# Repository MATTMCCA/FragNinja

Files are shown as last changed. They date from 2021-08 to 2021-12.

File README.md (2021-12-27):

# Frag-Ninja

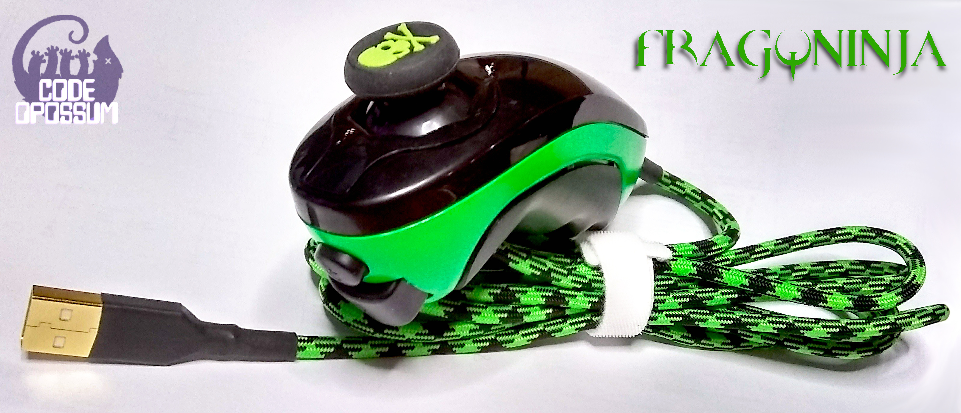
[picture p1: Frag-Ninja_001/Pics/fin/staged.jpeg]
STAGED


Wii Nunchuk 2 USB HID device, modchip repo. 

This board prototype should fit **in** a wii Nunchuk controller, ~~*I did not double check the clearance*~~.  

The Goal is to use the Nunchuk controller as a USB HID keyboard *OR* USB HID Gamepad, after connecting the *mod-chip*. 
The nunchuk also has 3 axis motion control. *(This, I'm not interested in)*.

[Digikey Cart with Reference Designators](https://www.digikey.com/short/zw3pv2)

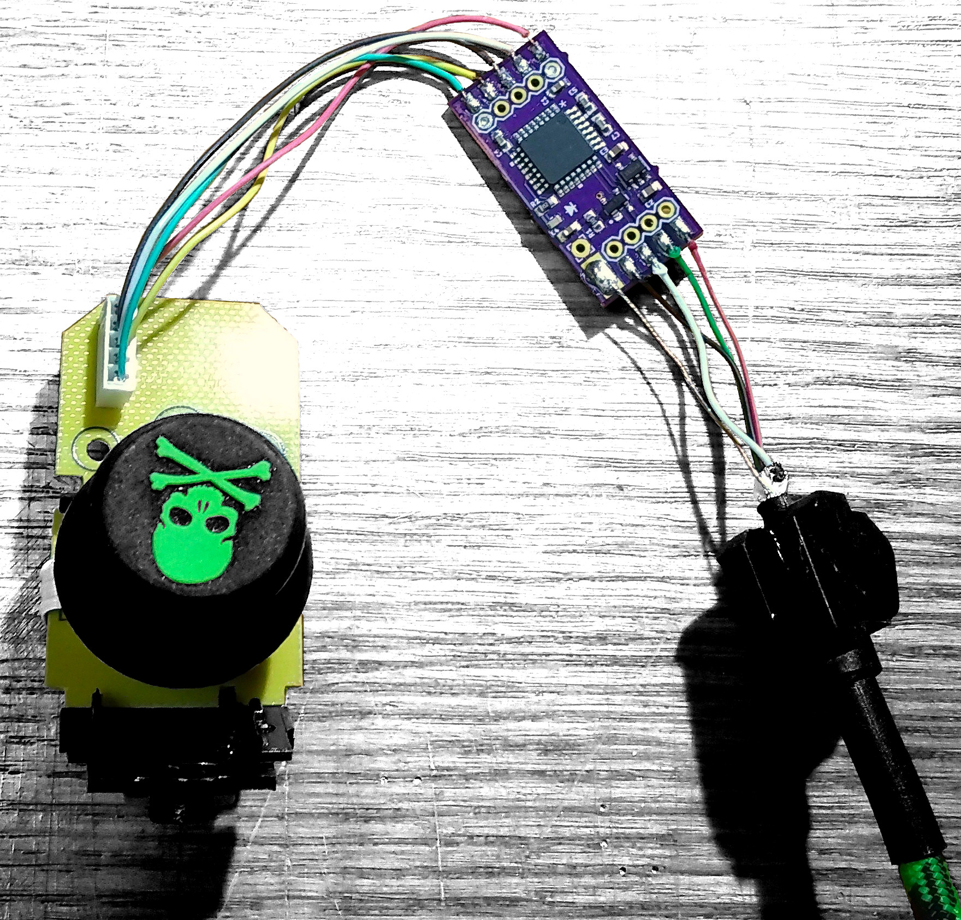
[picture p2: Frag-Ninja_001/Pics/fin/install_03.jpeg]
<p>

[*I'm not making kits, its too much work*](https://memegenerator.net/img/instances/65580880/not-sure-if-its-too-much-work-or-im-just-too-lazy.jpg)

---

### Notes
~~Using the the controllers attached cable is an option~~, but I opted for a new, longer, shielded, USB cable.

USB cable assembly parts purchased from [ZapCables.com](https://zapcables.com/diy-usb-cable-kit/)

- Cable length: ~~3ft~~, 6'
- USB Type-A connector (Gold Plated)
- Cord color: ~~'Acid Purple'~~, 'Viper'
- Double Sleeving: ~~Techflex, Ogre~~, None
- HeatShrink: ~~Purple~~, Black

Cable Build Guide: https://zapcables.com/content/zap-diy-usb-cable-kit-guide-v1.pdf

- **I think I linked the wrong LED in the BOM**.

---
### To Flash The Adafruit Bootloader

Solder Wires to **SWCLK & SWDIO**. Vref connects to pad **VCC** (this is 3.3vdc). Then supply 5vdc to the **5v** pad, and ground to the **GND** pad

I used this [Guide](https://learn.adafruit.com/how-to-program-samd-bootloaders/trinket-m0-wiring) & this [Guide](https://learn.adafruit.com/how-to-program-samd-bootloaders/programming-the-bootloader-with-atmel-studio) as a reference. Since Frag-Ninja is basically a clone of the *Trinket M0*, the procedure is exactly the same.

---

#### See Bill of Materials for board assembly part numbers.

- [Wii Nunchuck Controller](https://www.amazon.com/gp/product/B07RLBN9Z2)
- [Analog Thumb Stick Caps](https://www.amazon.com/gp/product/B07Q2B2VY4)
- [Skull Cap Covers](https://www.amazon.com/gp/product/B07GS95TD1)

### More Info
This 'mod-chip' is based on the *adafruit Trinket M0*, as a result I am able to use their boot-loader & arduino libs. This makes life just a tad bit easier (less code). 

*Big thanks to Adafriut for all of their hard work and great products.*

## Work in Progress

-  Boards have been ordered (9/13/2020)
   - BOARDS CAME! (9/26/2020)
---
-  Parts have been ordered (9/13/2020)
---
-  USB Cable kit has been ordered (9/13/2020)
   - *Cable Assembled, I should have got a 5' cable (9/17/2020)*
      - *was replaced with a 6' cable (9/23/2020)*
---	  
- **NEED TO ASSEMBLE THE PCB**
   - *PCB assembled (9/26/2020)*
---   
- **NEED TO BURN THE BOOTLOADER**
   - *Bootloader burned (9/26/2020)*
---   
- **NEED TO TEST THE HARDWARE**
   - *Tested and working (9/26/2020)*
---   
- **NEED TO FLASH CODE**
   - *Code tested & working (9/26/2020)*
---   
- **NEED TO HACK APART A WII Nunchuk**
   - *Gave a new white controller a fresh coat of lime green paint (9/24/2020)*
   - *Test fitted an **Xbox 360** after-market 'Analog Thumb Stick Cap' (9/24/2020)*.
   - *Frag-Ninja ModChip installed and working (9/26/2020)*
---
- **NEED TO FRAG!**



# WHY!?

Because I can't find a cheap joystick! I guess they aren't cool anymore or something.

# Copyright

Everything in this repo is released under Creative Commons Attribution-ShareAlike 2.5 Generic (CC BY-SA 2.5).

Comes as is, no warranty. I am also not responsible for any spontaneous time travel or combustion.

*Moved from my old repo*

### Borrowed works maintain original license.

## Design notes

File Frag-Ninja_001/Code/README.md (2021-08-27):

# Frag-Ninja

**Frag-Ninja** uses an ARM Cortex-M0+ SAM D21E from Microchip.

As lady luck would have it, there is Arduino core support for this chip. 

The provided code is written in C++, using Arduino libraries, see source headers for details.

### Notes

*I **HAVE** tested the code on the Frag-Ninja boards.*

#### HID GamePad Source Code
- Frag-Ninja_DPAD_8POS
- Frag-Ninja_JOYSTICK

#### HID Keyboard Source Code
- Frag-Ninja_KEYBOARD

## Why Arduino?
Because the hardware support is there, and its popular. OH! and the *OpenSource thing* helps too.

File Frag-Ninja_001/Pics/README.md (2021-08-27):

# Gallery

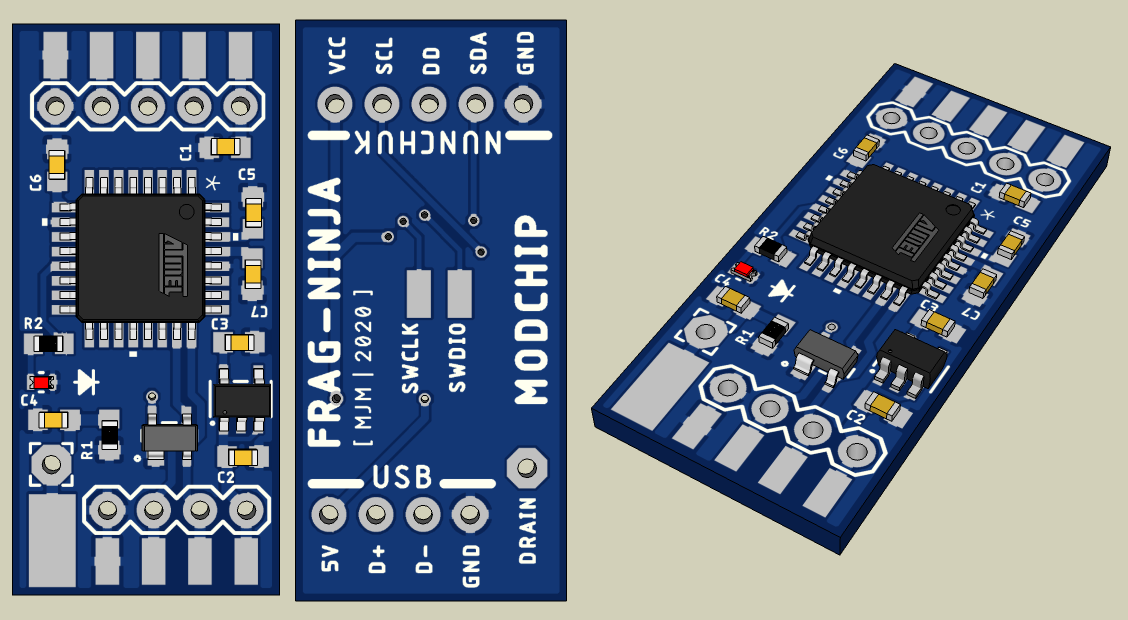
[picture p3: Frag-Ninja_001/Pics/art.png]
<p>

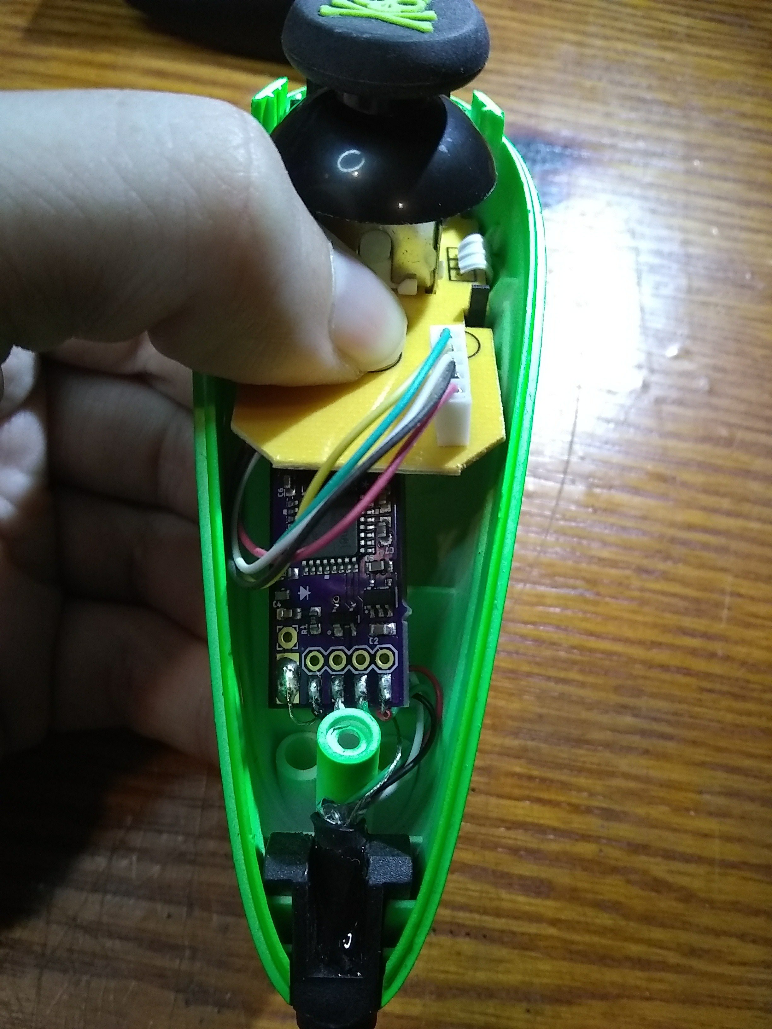
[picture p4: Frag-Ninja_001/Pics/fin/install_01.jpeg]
<p>

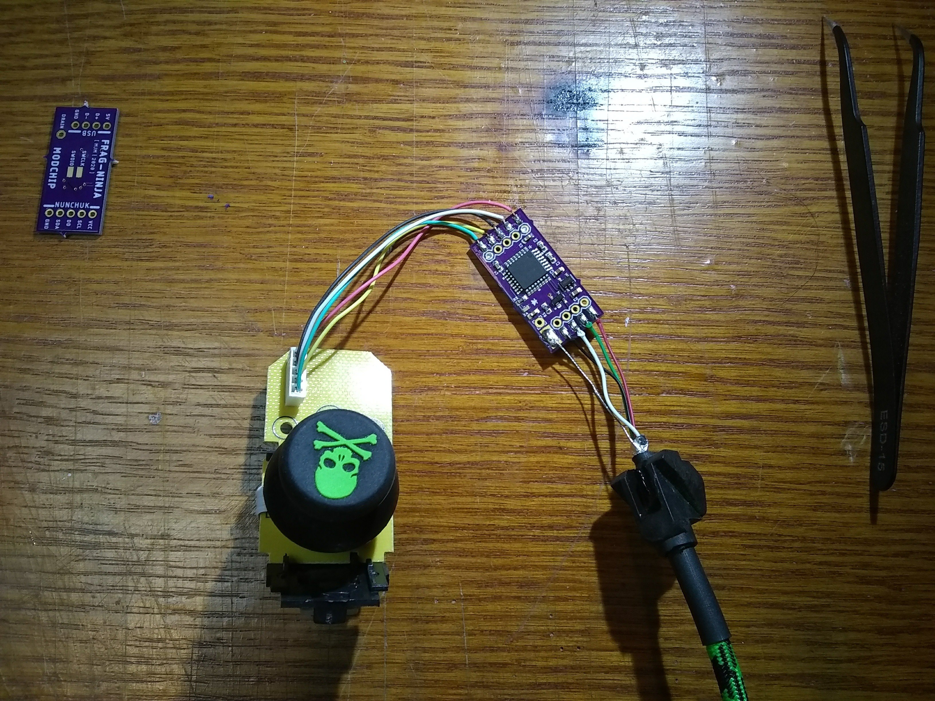
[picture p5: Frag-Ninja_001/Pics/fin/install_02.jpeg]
<p>

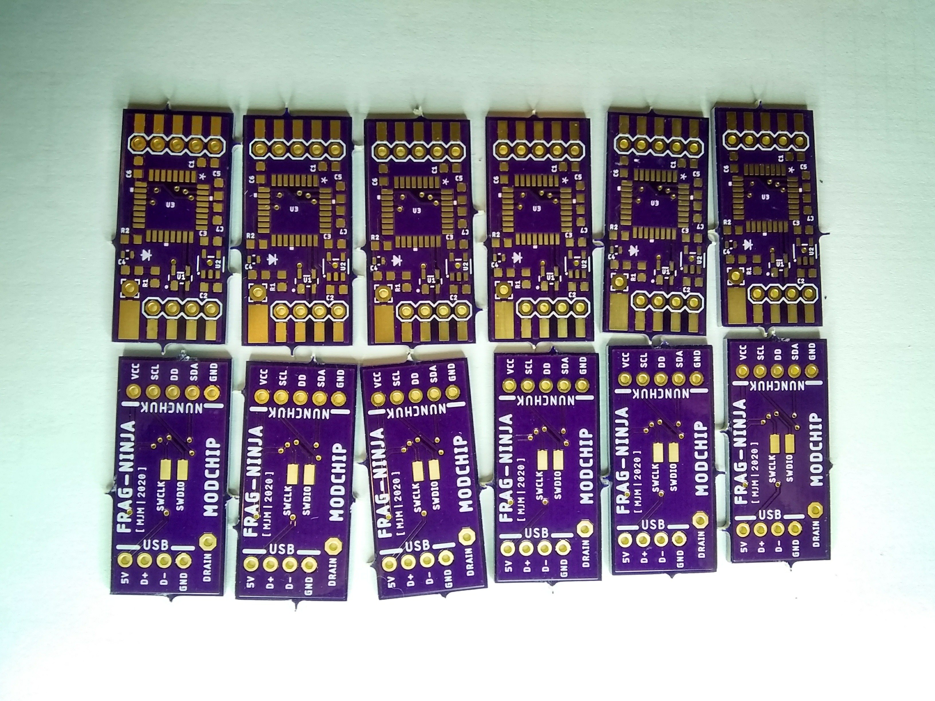
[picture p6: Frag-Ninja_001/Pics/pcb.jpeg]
<p>

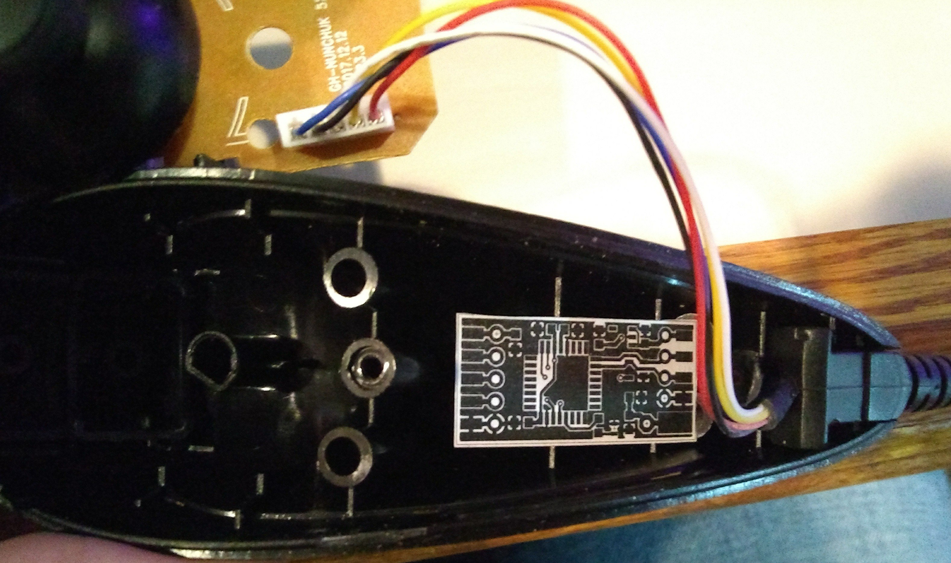
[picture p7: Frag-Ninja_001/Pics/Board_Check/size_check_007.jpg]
<p>

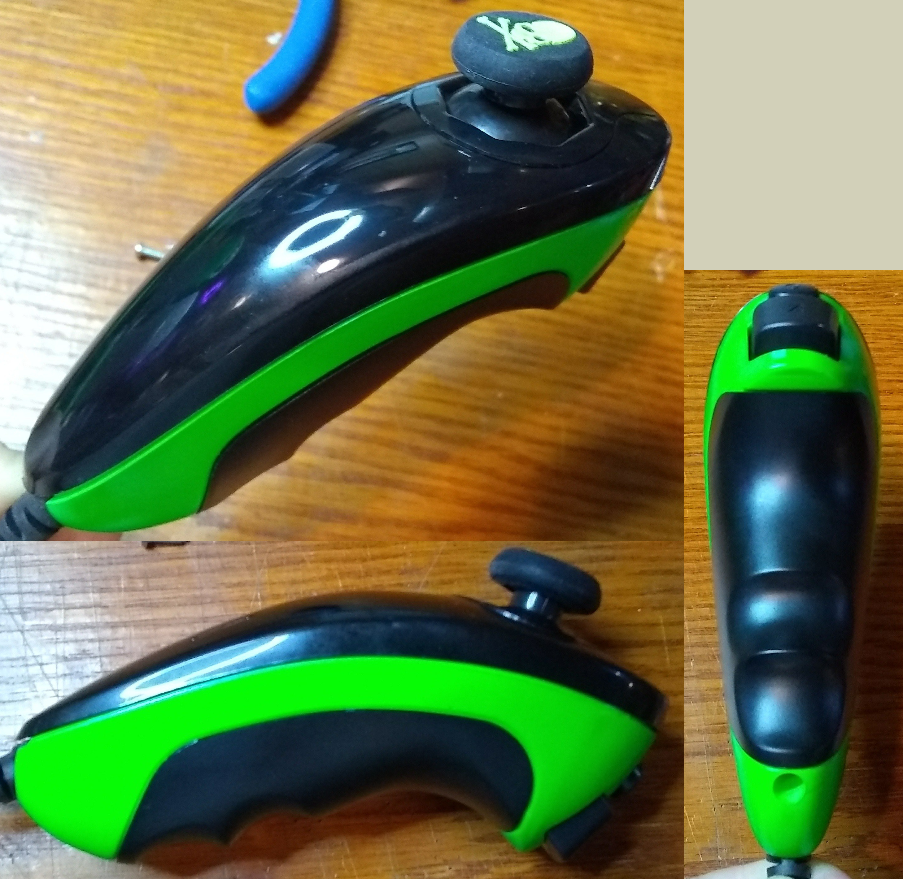
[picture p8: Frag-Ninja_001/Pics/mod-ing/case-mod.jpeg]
<p>

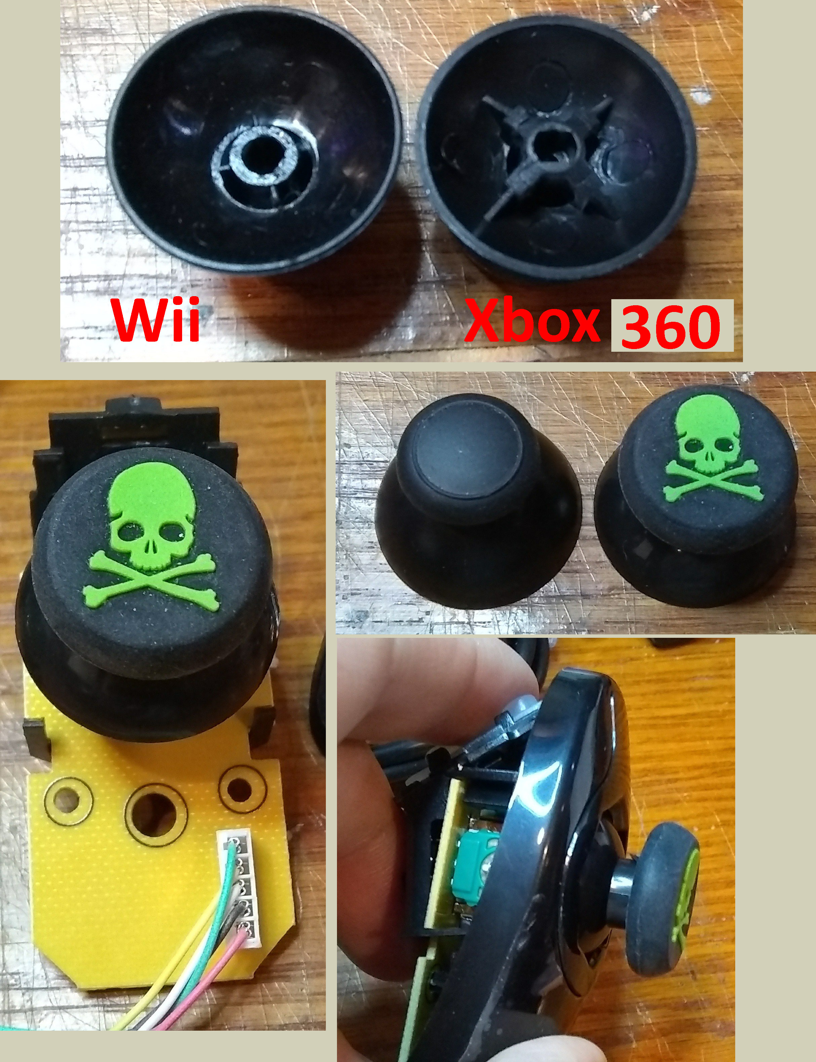
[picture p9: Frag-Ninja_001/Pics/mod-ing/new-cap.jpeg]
<p>

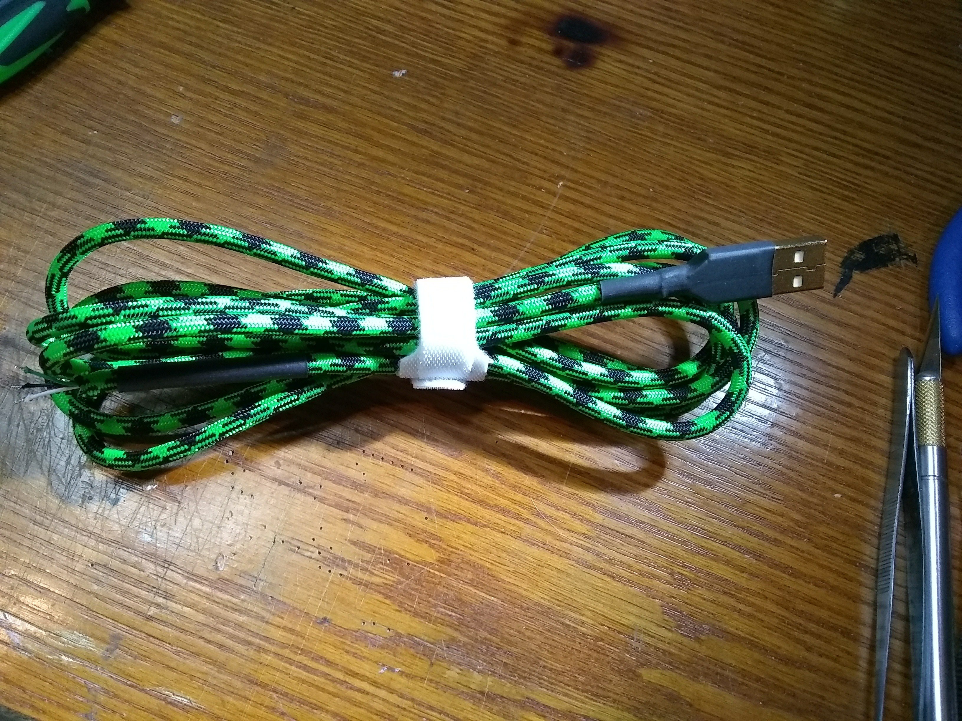
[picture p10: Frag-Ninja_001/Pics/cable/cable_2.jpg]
<p>

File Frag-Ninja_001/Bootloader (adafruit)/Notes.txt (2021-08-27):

- Notes -
https://learn.adafruit.com/how-to-program-samd-bootloaders/programming-the-bootloader-with-atmel-studio
https://learn.adafruit.com/how-to-program-samd-bootloaders/trinket-m0-wiring

https://learn.adafruit.com/assets/45723
https://www.adafruit.com/product/3500

- Bootloader -
https://github.com/adafruit/uf2-samdx1/releases/tag/v3.10.0

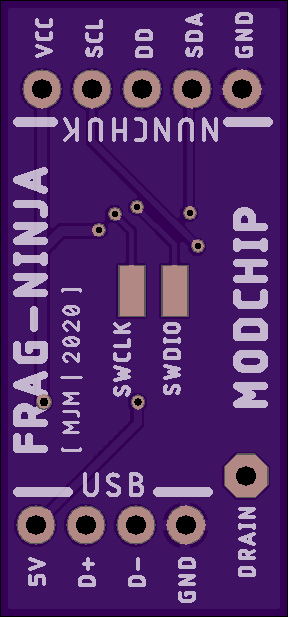
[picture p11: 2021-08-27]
Frag-Ninja_001/Pics/oshpark_back.png

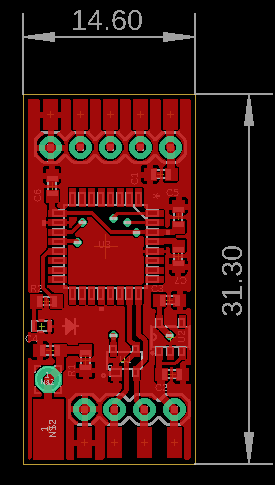
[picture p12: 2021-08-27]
Frag-Ninja_001/Pics/BRD_TOP.png

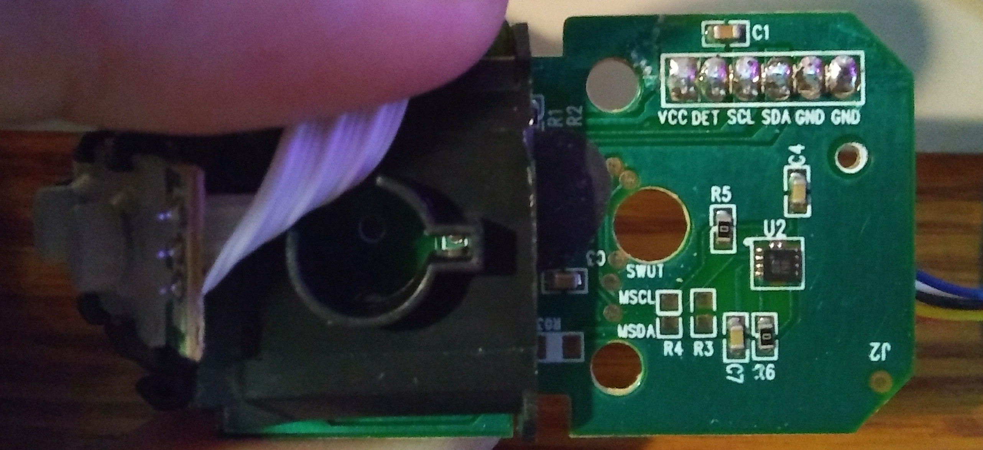
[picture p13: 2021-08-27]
Frag-Ninja_001/Pics/Board_Check/size_check_004.jpg

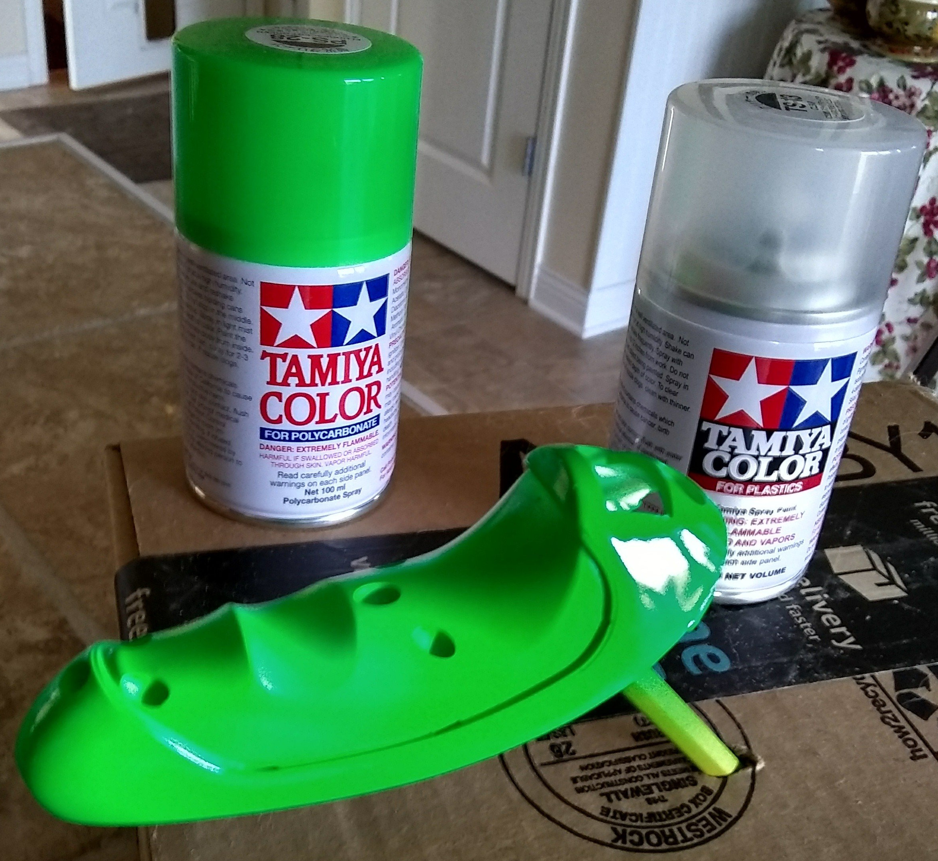
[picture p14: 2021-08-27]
Frag-Ninja_001/Pics/mod-ing/paint.jpeg

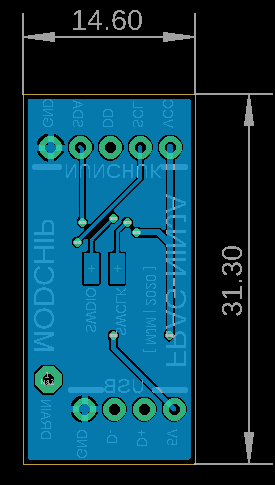
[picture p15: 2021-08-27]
Frag-Ninja_001/Pics/BRD_BOT.png

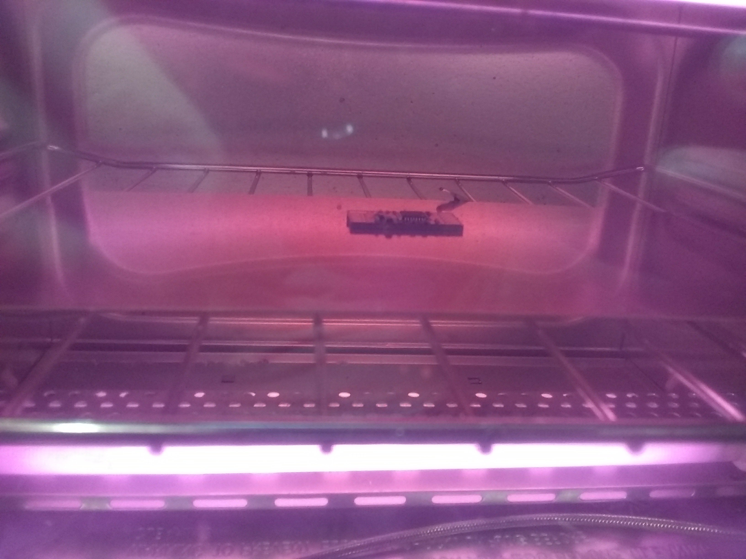
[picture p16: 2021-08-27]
Frag-Ninja_001/Pics/Board_Check/reflow.jpeg

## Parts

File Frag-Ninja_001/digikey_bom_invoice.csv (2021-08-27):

Index | Quantity | Part Number | Manufacturer Part Number | Description | Customer Reference | Backorder | Unit Price | Extended Price
1 | 50 | 1276-1182-1-ND | CL10A105KP8NNNC | CAP CER 1UF 10V X5R 0603 | C1, C5, C6, C7 | 0 | 0.0208 | $1.04
2 | 10 | 445-14258-1-ND | C1608X7S1A475K080AC | CAP CER 4.7UF 10V X7S 0603 | C2, C3 | 0 | 0.174 | $1.74
3 | 50 | 399-1087-1-ND | C0603C472K5RACTU | CAP CER 4700PF 50V X7R 0603 | C4 | 0 | 0.0226 | $1.13
4 | 10 | SML-D12U1WT86CT-ND | SML-D12U1WT86 | LED RED DIFFUSED 1608 SMD | LED1 | 0 | 0.147 | $1.47
5 | 10 | A130452CT-ND | CRGP0603F1M0 | CRGP 0603 1M0 1% | R1 | 0 | 0.121 | $1.21
6 | 100 | A130092CT-ND | CRGCQ0603J1K5 | CRGCQ 0603 1K5 5% | R2 | 0 | 0.0083 | $0.83
7 | 5 | 1727-3884-1-ND | PRTR5V0U2X,215 | TVS DIODE 5.5V SOT143B | U1 | 0 | 0.51 | $2.55
8 | 5 | AP7365-33WG-7DICT-ND | AP7365-33WG-7 | IC REG LINEAR 3.3V 600MA SOT25 | U2 | 0 | 0.42 | $2.10
9 | 3 | ATSAMD21E18A-AU-ND | ATSAMD21E18A-AU | IC MCU 32BIT 256KB FLASH 32TQFP | U3 | 0 | 2.91 | $8.73
 |  |  |  |  |  |  | Subtotal | $20.80

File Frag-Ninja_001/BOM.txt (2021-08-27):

Partlist

Exported from FN_001.sch at 9/13/2020 12:08 AM

EAGLE Version 9.5.0 Copyright (c) 1988-2019 Autodesk, Inc.

Assembly variant: 

Part     Value               Device              Package        Library             Sheet       Digikey Part#

C1       1uF                 C-EUC0603K          C0603K         rcl                 1           1276-1182-1-ND

C2       4.7uF               C-EUC0603K          C0603K         rcl                 1           445-14258-1-ND
C3       4.7uF               C-EUC0603K          C0603K         rcl                 1           445-14258-1-ND

C4       4.7nF               C-EUC0603K          C0603K         rcl                 1           399-1087-2-ND

C5       1uF                 C-EUC0603K          C0603K         rcl                 1           1276-1182-1-ND
C6       1uF                 C-EUC0603K          C0603K         rcl                 1           1276-1182-1-ND
C7       1uF                 C-EUC0603K          C0603K         rcl                 1           1276-1182-1-ND

LED1     RED                 SML-D12U1WT86       LED_SMLD12_ROM SML-D12U1WT86       1           SML-D12U1WT86CT-ND

R1       1M                  R-US_R0603          R0603          rcl                 1           A130452CT-ND

R2       1.5K                R-US_R0603          R0603          rcl                 1           A130092CT-ND

U1       PRTR5V0U2X,215      PRTR5V0U2X          SOT143B_NXP    PRTR5V0U2X          1           1727-3884-1-ND

U2       AP7365-33WG-7       AP7365-33WG-7       SOT25_DIO      AP7365-33WG-7       1           AP7365-33WG-7DICT-ND

U3       ATSAMD21E18A-AU     ATSAMD21E18A-AU     TQFP32_MC_MCH  ATSAMD21E18A-AU     1           ATSAMD21E18A-AU-ND

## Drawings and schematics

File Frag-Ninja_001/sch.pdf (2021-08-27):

A

A

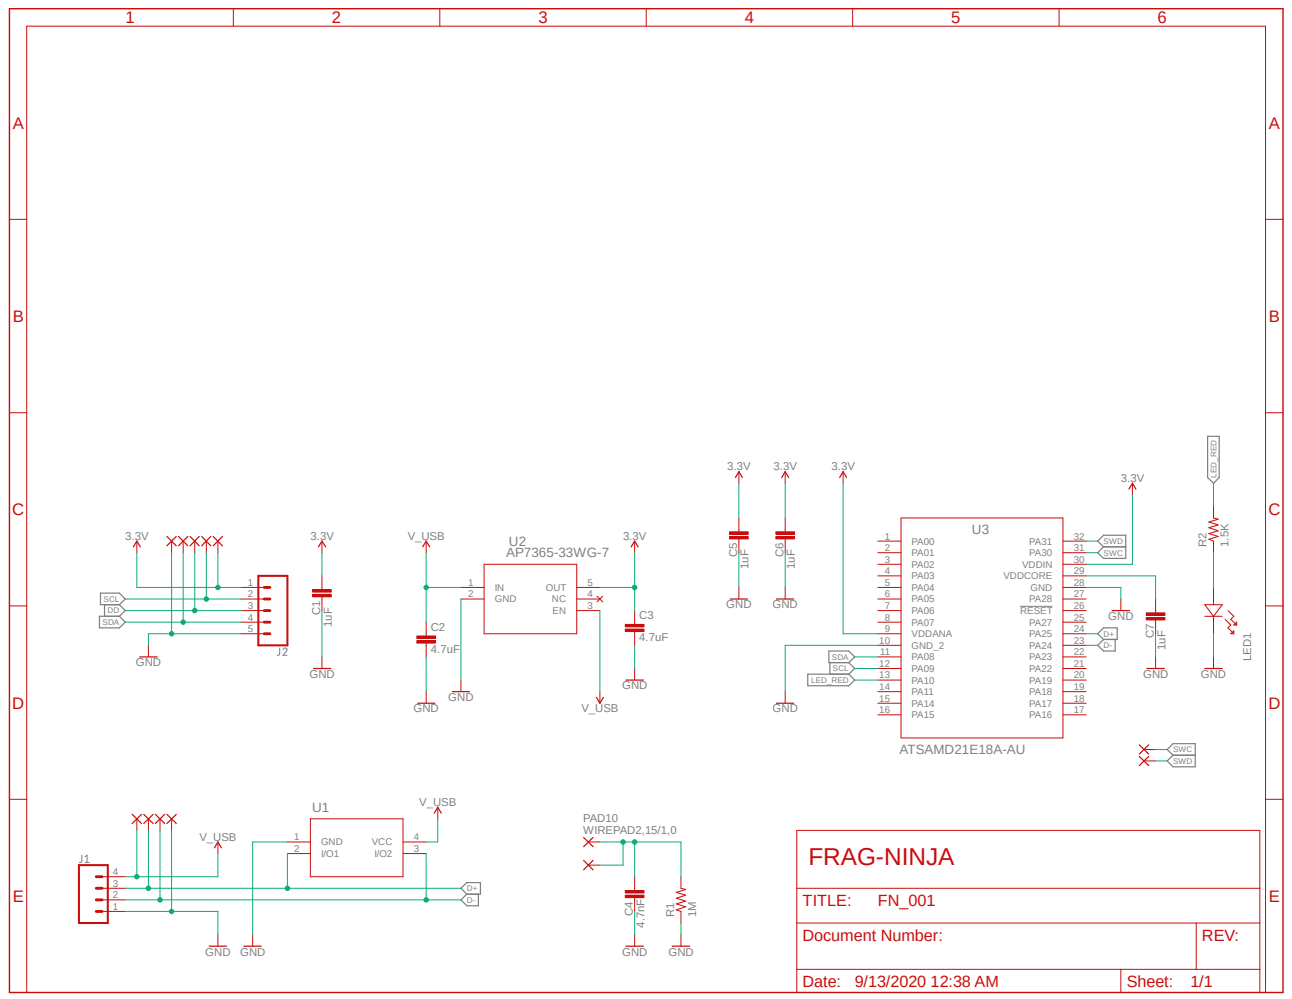
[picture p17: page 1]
V_USB; WIREPAD2,15/1,0 4.7nF; GND; ATSAMD21E18A-AU; GND ¹uF; V_USB GND 1; 3 VCC; PAD10 C⁴; VDDANA 9; GND_2 10; 25 RESET; 27 GND; 28 VDDCORE; 29 VDDIN; LED¹ C⁵; GND 2; 4 OUT; D- SCL; SCL DD; SDA; SWD; SWC; LED_RED; FRAG-NINJA

2 | | TITLE: FN_001
1 | GND

Document Number: | REV:

Date: 9/13/2020 12:38 AM | Sheet: 1/1

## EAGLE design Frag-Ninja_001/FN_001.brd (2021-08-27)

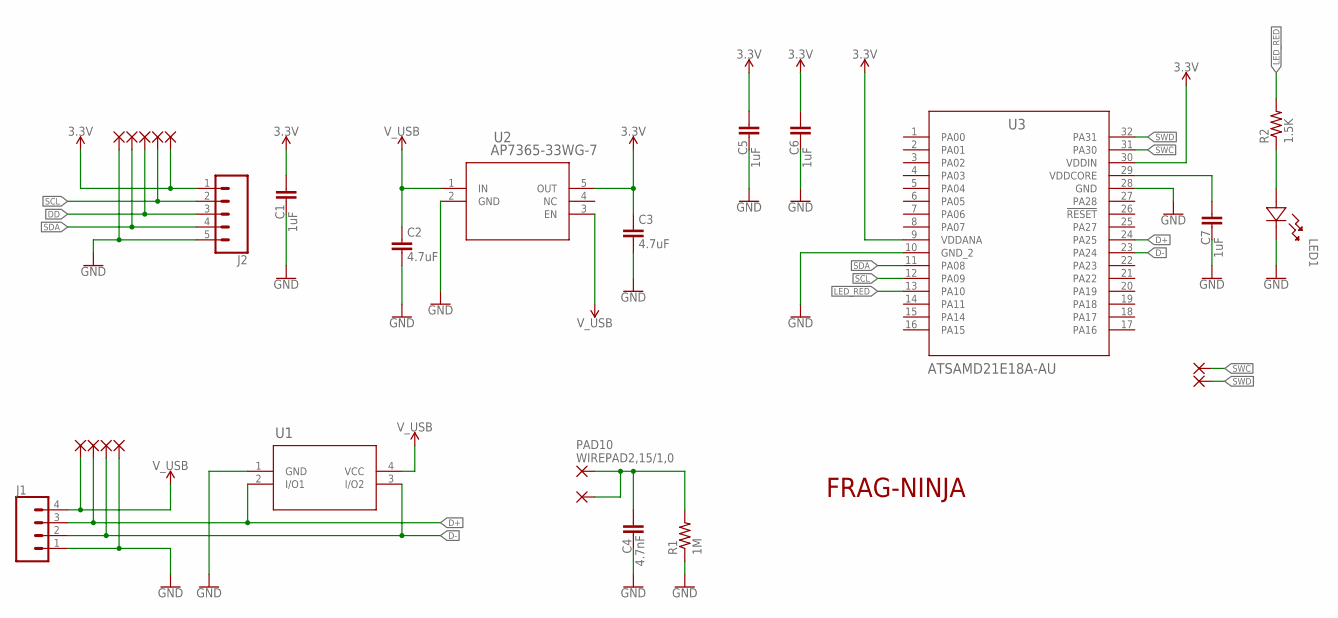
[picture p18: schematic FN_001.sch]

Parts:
C1, C5, C6, C7: 1uF; C0603K
C2, C3: 4.7uF; C0603K
C4: 4.7nF; C0603K
J1: CONN_04PTH; 1X04
J2: CONN_05; 1X05
LED1: SML-D12U1WT86; LED_SMLD12_ROM
PAD1, PAD2, PAD3, PAD4, PAD5, PAD6, PAD7, PAD8, PAD9, PAD12, PAD13: WIREPADSMD1,27-254; SMD1,27-2,54
PAD10: WIREPAD2,15/1,0; 2,15/1,0
PAD11: WIREPADSMD2,54-5,08; SMD2,54-5,08
R1: 1M; R0603
R2: 1.5K; R0603
U1: PRTR5V0U2X; SOT143B_NXP
U2: AP7365-33WG-7; SOT25_DIO
U3: ATSAMD21E18A-AU; TQFP32_MC_MCH

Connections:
3.3V: C1.1, C3.1, C5.1, C6.1, J2.1, PAD9.1, U2.5 (OUT), U3.9 (VDDANA), U3.30 (VDDIN)
D+: J1.3, PAD2.1, U1.2 (I/O1), U3.24 (PA25)
D-: J1.2, PAD3.1, U1.3 (I/O2), U3.23 (PA24)
DD: J2.3, PAD7.1
GND: C1.2, C2.2, C3.2, C4.2, C5.2, C6.2, C7.2, J1.1, J2.5, LED1.1, PAD4.1, PAD5.1, R1.1, U1.1 (GND), U2.2 (GND), U3.10 (GND_2), U3.28 (GND)
LED_RED: R2.2, U3.13 (PA10)
unnamed: LED1.2, R2.1
unnamed: C4.1, PAD10.1, PAD11.1, R1.2
unnamed: C7.1, U3.29 (VDDCORE)
SCL: J2.2, PAD8.1, U3.12 (PA09)
SDA: J2.4, PAD6.1, U3.11 (PA08)
SWC: PAD12.1, U3.31 (PA30)
SWD: PAD13.1, U3.32 (PA31)
V_USB: C2.1, J1.4, PAD1.1, U1.4 (VCC), U2.1 (IN), U2.3 (EN)

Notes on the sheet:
FRAG-NINJA

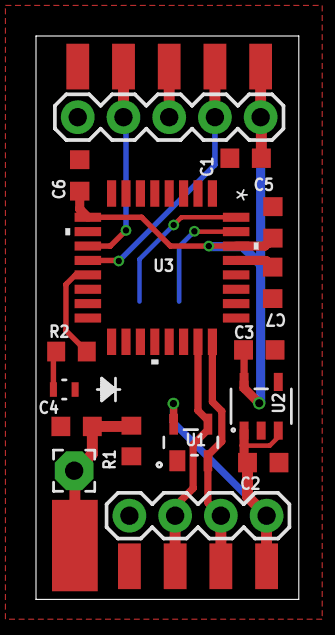
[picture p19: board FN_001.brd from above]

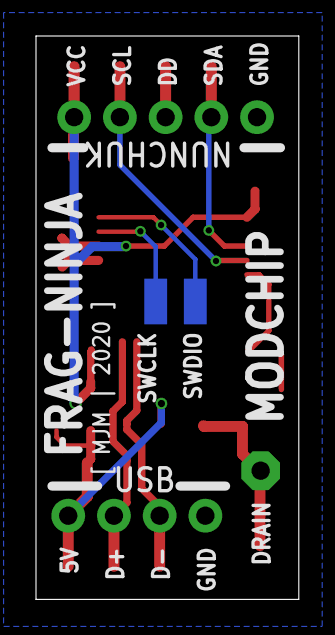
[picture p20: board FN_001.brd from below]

Board: 2 copper layers, 14.6 x 31.3 mm, 28 parts (2 on the bottom side), 14 nets.

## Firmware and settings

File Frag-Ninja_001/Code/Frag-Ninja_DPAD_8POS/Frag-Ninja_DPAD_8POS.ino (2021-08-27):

/******* TESTED ON ACTUAL HARDWARE *******

   Frag-Firmware | MJM | 9/26/2020

   Shows up as HID Gamepad [DPAD Control]

   REF: https://github.com/dmadison/NintendoExtensionCtrl
        https://github.com/NicoHood/HID
        https://github.com/NicoHood/HID/issues/194

   Notes: Red LED Indicates Nunchuk Connection Failure (cycle power)

   Runs on Unofficial Test Hardware (9/26/2020)
   Runs on Frag-Ninja (9/26/2020)

 ******* TESTED ON ACTUAL HARDWARE *******/

#include "HID-Project.h"
#include <NintendoExtensionCtrl.h>

#define DEAD_ZONE       5
#define NULL_STICK      128 // center pos
#define _POSITIVE       (NULL_STICK + DEAD_ZONE)
#define _NEGITIVE       (NULL_STICK - DEAD_ZONE)

Nunchuk nchuk;
bool LED = LOW;

void setup() {
  // put your setup code here, to run once:
  digitalWrite(LED_BUILTIN, HIGH);
  nchuk.begin();
  Gamepad.begin();
  while (!nchuk.connect()) delay(1000);
}

void loop() {
  // put your main code here, to run repeatedly:
  bool success = nchuk.update();
  if (!success) {
    delay(1000);
  }
  else {
    bool zButton = nchuk.buttonZ();
    bool cButton = nchuk.buttonC();
    int joyY = nchuk.joyY();
    int joyX = nchuk.joyX();

    bool state[4] = {false};
    state[0] = (joyY >= _POSITIVE) ? true : false; /* UP */
    state[1] = (joyY <= _NEGITIVE) ? true : false; /* DOWN */
    state[2] = (joyX >= _POSITIVE) ? true : false; /* RIGHT */
    state[3] = (joyX <= _NEGITIVE) ? true : false; /* LEFT */

    uint8_t dpad1 = GAMEPAD_DPAD_CENTERED;    // 0
    if (state[0]) dpad1 = GAMEPAD_DPAD_UP;    // 1
    if (state[2]) dpad1 = GAMEPAD_DPAD_RIGHT; // 3
    if (state[1]) dpad1 = GAMEPAD_DPAD_DOWN;  // 5
    if (state[3]) dpad1 = GAMEPAD_DPAD_LEFT;  // 7
    if (state[0] & state[2]) dpad1 = GAMEPAD_DPAD_UP_RIGHT;   // 2
    if (state[1] & state[2]) dpad1 = GAMEPAD_DPAD_DOWN_RIGHT; // 4
    if (state[1] & state[3]) dpad1 = GAMEPAD_DPAD_DOWN_LEFT;  // 6
    if (state[0] & state[3]) dpad1 = GAMEPAD_DPAD_UP_LEFT;    // 8

    cButton == true ? Gamepad.press(1) : Gamepad.release(1);
    zButton == true ? Gamepad.press(2) : Gamepad.release(2);

    Gamepad.dPad1(dpad1);
    Gamepad.write();
  }

  if (success != LED) {
    LED = success;
    digitalWrite(LED_BUILTIN, !LED);
  }
}

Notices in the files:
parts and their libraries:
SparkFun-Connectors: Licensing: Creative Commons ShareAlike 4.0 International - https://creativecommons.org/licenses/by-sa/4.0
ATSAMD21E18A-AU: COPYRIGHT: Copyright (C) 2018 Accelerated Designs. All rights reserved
